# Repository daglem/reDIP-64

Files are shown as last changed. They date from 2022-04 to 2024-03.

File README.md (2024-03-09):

# reDIP 64

## Commodore 64 FPGA emulation platform
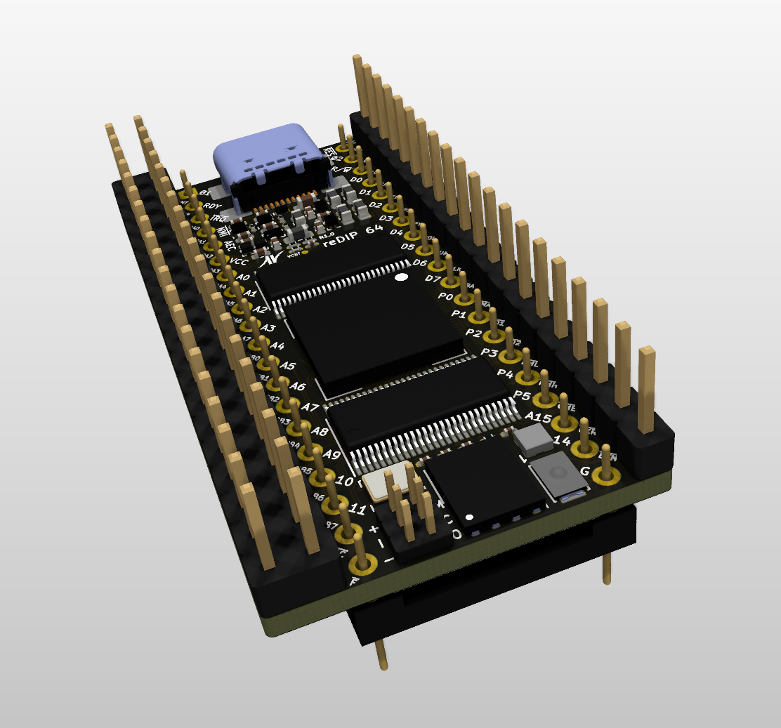
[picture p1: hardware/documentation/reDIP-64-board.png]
Board


## Overview

The reDIP 64 is an open source hardware development board which
combines the following in a tiny 25.40 x 50.80 mm footprint:

* Lattice ECP5-5G FPGA (LFE5UM5G-25)
* NXP PTN5110NHQ USB PD TCPC PHY
* NXP SGTL5000 Audio Codec
* 128Mbit FLASH
* 128Mbit HyperRAM
* RGB LED
* Push button
* USB-C receptacle for power, Full Speed USB, and DisplayPort (DP Alt Mode)
* Lots of 5V tolerant I/O

The reDIP 64 aims at functioning as

* A partial or full brain transplant for the venerable Commodore 64
* A "Retro computer on a chip", which can be used stand-alone or in
  custom retro computer builds
* A versatile generic FPGA platform with power, HID input, and audio /
  video output all handled through a single USB-C connector

Designs for the ECP5 FPGA can be processed by
[yosys](https://github.com/YosysHQ/yosys/) and
[nextpnr](https://github.com/YosysHQ/nextpnr/).

Also check out the [reDIP SID](https://github.com/daglem/reDIP-SID),
if you are interested in a platform for MOS 6581 / 8580 SID emulation
in particular.

## General use

### I/O interfaces

#### 100 header pins:

* 5V input / output
* 3.3V output
* 92 FPGA GPIO
* 5 audio pins (stereo line input, stereo line output, GND)
* GND

All FPGA I/O is 5V tolerant, and can drive 5V TTL.

Note that the audio line inputs are not AC coupled - AC coupling must
be externally added for audio applications. Without external AC
coupling, the line inputs can conceivably be used as generic ADCs.

#### JTAG:

A separate 6 pin header is provided for JTAG.

#### USB-C functions:

* 5V power in / out
* USB Power Delivery (PD)
* FPGA Full Speed USB
* FPGA DisplayPort (DP Alt Mode)

## Commodore 64 compatibility

The board is pin compatible with the MOS 6510 / 8500 MPU chip, and has
additional pin headers to cover all the custom chips and I/O in the
Commodore 64:

* 6510 / 8500 MPU
* 6567/6569 / 8562/8565 VIC-II
* 6581 / 8580 SID (x 2)
* 2 x 6526 CIA
* Cartridge port signals
* Menu / freeze button

For anyone interested in experimenting with a Commodore 64 setup,
while avoiding blown fuses and a broken reDIP 64 board:

* A 2A C64 power supply is recommended
* Be careful not to apply force to SMD components on insertion and removal - use a ZIF socket if possible

The idea is that one can start by mounting the reDIP 64 in a Commodore
64, replacing the 6510 / 8500 MPU. This will make it possible to communicate
with the Commodore 64 via USB, to output audio and video via the USB-C
connector (DP Alt Mode), and to emulate a second SID chip.

Then, if one wishes to replace the VIC-II, the SID, or a CIA chip, the
custom chip is removed, and wires are run from the reDIP 64 to the
corresponding socket pins for the custom chip.

Note that the audio line outputs cannot drive the C64 audio output
stage directly, however an audio output may be connected directly to
pin 3 of the C64 audio/video connector (preferably removing or cutting
a pin on C13 in the C64).

Also note that unless suggested GPIO is repurposed for other
functions, the VIC-II can only be replaced by additionally emulating
all RAM chips, and the PLA can only be replaced by emulating *all*
custom chips, including ROM and RAM.

The MOS 8502 MPU used in the Commodore C128 has a similar pinout to
the MOS 6510. Since the same pins are used for power, the reDIP 64 can
conceivably also be used in a C128.

## Retro computer on a chip

Power, HID input, and audio / video can all be handled via the USB-C
port, hence the reDIP 64 is in fact capable of operating as a retro
computer all on its own. Just connect the reDIP 64 to a DisplayPort
monitor, either directly or via an USB hub, and add a keyboard and any
other HID input devices. Now, all that is needed is an FPGA
implementation of a retro computer :wink:

To create a fully functional retro computer, i.e. with I/O which can
interface with original perhiperals, physical connectors and glue
logic must be added to the mix. This can make for some fun projects!

Using the suggested GPIO, a fully functional custom C64 can be built
using a minimum of additional components.

## Other FPGA projects

The board can be of course also be used to experiment with e.g.

* DisplayPort audio / video
* Analog audio
* USB Power Delivery
* Interfacing with 5V TTL
* RISC-V and other CPU architectures
* Other SoC projects

## Disclaimer

Please note that this is only my third board design - rookie mistakes
are probably made, and feedback is welcome.

## Board images

Board Front | Board Back
----------- | ----------
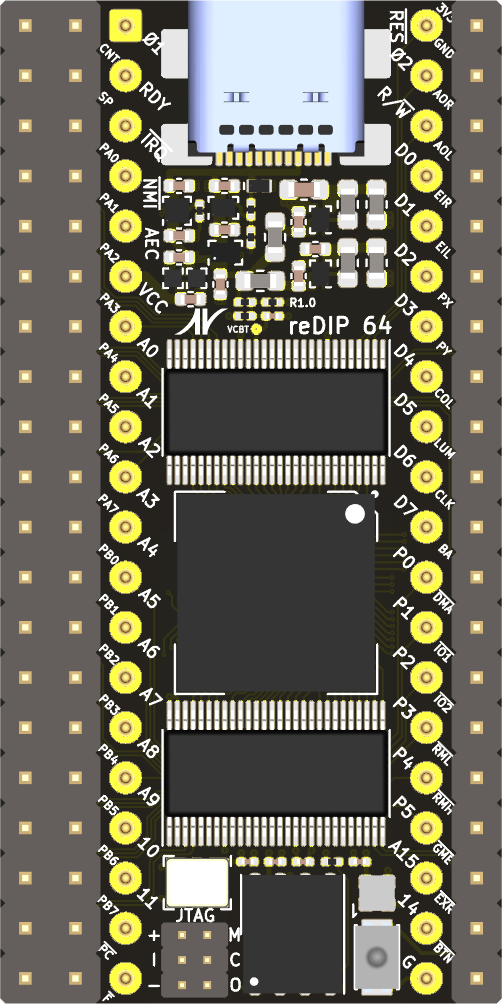
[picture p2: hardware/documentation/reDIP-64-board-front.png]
Board Front
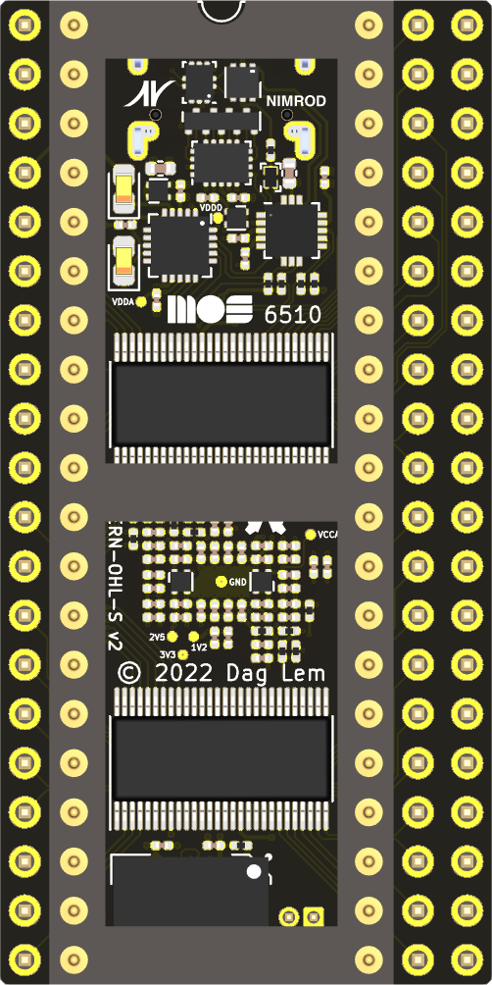
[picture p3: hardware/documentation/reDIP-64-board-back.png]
Board Back
 |

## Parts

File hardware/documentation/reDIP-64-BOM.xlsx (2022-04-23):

Prj: | reDIP 64 |  |  |  |  |  |  | Board Qty: | 100
Co.: | Nimrod |  |  |  |  |  |  | Unit Cost: | $30.45
Prj date: | lø. 23. april 2022 kl. 17.23 +0200 |  |  |  |  |  |  | Total Cost: | $3045.41 |  |  |  |  | $1220.08 | 22 of 53 parts found |  |  |  |  | $3181.63 | 52 of 53 parts found |  |  |  |  | $1467.26 | 38 of 53 parts found |  |  |  |  | $209.65 | 11 of 53 parts found |  |  |  |  | $2558.30 | 45 of 53 parts found |  |  |  |  | $1634.90 | 39 of 53 parts found |  |  |  |  | $346.20 | 18 of 53 parts found |  |  |  |  | $60.64 | 4 of 53 parts found
$ date: | 2022-04-23 17:23:41
Global Part Info |  |  |  |  |  |  |  |  |  | Arrow |  |  |  |  |  | Digi-Key |  |  |  |  |  | Farnell |  |  |  |  |  | LCSC |  |  |  |  |  | Mouser |  |  |  |  |  | Newark |  |  |  |  |  | RS Components |  |  |  |  |  | TME
Refs | Value | Desc | Notes | Footprint | Manf | Manf# | Qty | Unit$ | Ext$ | Avail | Purch | Unit$ | MOQ | Ext$ | Cat# | Avail | Purch | Unit$ | MOQ | Ext$ | Cat# | Avail | Purch | Unit$ | MOQ | Ext$ | Cat# | Avail | Purch | Unit$ | MOQ | Ext$ | Cat# | Avail | Purch | Unit$ | MOQ | Ext$ | Cat# | Avail | Purch | Unit$ | MOQ | Ext$ | Cat# | Avail | Purch | Unit$ | MOQ | Ext$ | Cat# | Avail | Purch | Unit$ | MOQ | Ext$ | Cat#
C1,C13,C19 | 1uF | CAP CER 2.2uF 25V 20% X5R 0402 | 5V DC DERATED TO 1uF | C_0402_1005Metric | Murata | GRM155R61E225ME11D (https://www.murata.com/products/productdetail.aspx?partno=GRM155R61E225ME11D) | 300 | $0.035 | $10.56 | 41127 |  | $0.092 | 1 | $27.63 | GRM155R61E225ME11D (https://octopart.com/click/track?ai=8078&sig=0bf2f55&sid=1106&ppid=46692831&vpid=473331984&ct=offers) | 163798 |  | $0.096 | 1 | $28.83 | 490-12704-1-ND (https://octopart.com/click/track?ai=8078&sig=00769d9&sid=459&ppid=46692831&vpid=242051473&ct=offers) | 20000 |  | $0.099 | 10 | $29.77 | 3582801 (https://octopart.com/click/track?c=1&ai=8078&sig=0068366&sid=819&ppid=46692831&vpid=670691908&ct=offers) | 6980 |  | $0.035 | 10 | $10.56 | C385033 (https://octopart.com/click/track?ai=8078&sig=05f9ad3&sid=27971&ppid=46692831&vpid=791860132&ct=offers) | 247394 |  | $0.100 | 1 | $30.00 | 81GRM155R61E225ME1D (https://octopart.com/click/track?ai=8078&sig=075e695&sid=2401&ppid=46692831&vpid=202849811&ct=offers) | 20000 |  | $0.100 | 1 | $30.00 | 03AJ1583 (https://octopart.com/click/track?c=1&ai=8078&sig=0cd1567&sid=2402&ppid=46692831&vpid=671481202&ct=offers)
C2,C4,C24,C26,C30,C31,C37,C39,C41,C43,C45,C47,C49,C51,C53,C55,C57,C61 | 1uF | CAP CER 2.2uF 6.3V 20% X5R 0201 | C24,C30: 1.2V DC DERATED TO 1.4uF C26: 2.5V DC DERATED TO 0.9uF C2,C4,C31,C37,C39,C41,C43,C45,C47,C49,C51,C53,C55,C57,C61: 3.3V DC DERATED TO 0.7uF | C_0201_0603Metric | Murata | GRM033R60J225ME01D (https://www.murata.com/products/productdetail.aspx?partno=GRM033R60J225ME01D) | 1800 | $0.029 | $51.84 |  |  |  |  |  |  | 11380 |  | $0.038 | 1 | $68.31 | 490-GRM033R60J225ME01DCT-ND (https://octopart.com/click/track?ai=8078&sig=07d2518&sid=459&ppid=111800792&vpid=790821740&ct=offers) |  |  |  |  |  |  | 12020 |  | $0.029 | 10 | $51.84 | C782150 (https://octopart.com/click/track?ai=8078&sig=014ed64&sid=27971&ppid=111800792&vpid=658813846&ct=offers) | 670 |  | $0.044 | 1 | $79.20 | 81GRM033R60J225ME1D (https://octopart.com/click/track?ai=8078&sig=0ead83f&sid=2401&ppid=111800792&vpid=707177137&ct=offers)
C3,C23,C25,C28,C29 | 1uF | CAP CER 2.2uF 10V 20% X5R 0201 | C23,C25,C28,C29: 3.3V DC DERATED TO 0.9uF C3: 5V DC DERATED TO 0.6uF | C_0201_0603Metric | Murata | GRM035R61A225ME01D (https://www.murata.com/products/productdetail.aspx?partno=GRM035R61A225ME01D) | 500
C5,C7-C11 | 100nF | CAP CER 100nF 6.3V 10% X5R 0201 |  | C_0201_0603Metric | Murata | GRM033R60J104KE19D (https://www.murata.com/products/productdetail.aspx?partno=GRM033R60J104KE19D) | 600 | $0.002 | $1.20 | 3960000 |  |  | 15000 |  | GRM033R60J104KE19D (https://octopart.com/click/track?ai=8078&sig=036c01f&sid=1106&ppid=196787&vpid=15059944&ct=offers) | 30960551 |  | $0.006 | 1 | $3.85 | 490-3167-1-ND (https://octopart.com/click/track?ai=8078&sig=0350220&sid=459&ppid=196787&vpid=1550152&ct=offers) | 105000 |  | $0.049 | 10 | $29.70 | 1775994 (https://octopart.com/click/track?ai=8078&sig=05fdde2&sid=819&ppid=196787&vpid=139136007&ct=offers) | 2617600 |  | $0.002 | 100 | $1.20 | C76928 (https://octopart.com/click/track?ai=8078&sig=0fec319&sid=27971&ppid=196787&vpid=445986843&ct=offers) | 6447225 |  | $0.009 | 1 | $5.40 | 81GRM033R60J104KE19 (https://octopart.com/click/track?ai=8078&sig=013ebb0&sid=2401&ppid=196787&vpid=38925187&ct=offers) | 105000 |  | $0.012 | 1 | $7.20 | 51R6558 (https://octopart.com/click/track?ai=8078&sig=09cce70&sid=2402&ppid=196787&vpid=20869753&ct=offers) |  |  |  |  |  |  | 25600 |  | $0.013 | 100 | $7.50 | GRM033R60J104KE19D (https://octopart.com/click/track?ai=8078&sig=079c19d&sid=1532&ppid=196787&vpid=709097614&ct=offers)
C6,C32-C36,C38,C40,C42,C44,C46,C48,C50,C52,C54,C56,C58-C60,C62-C68 | 0.1uF | CAP CER 0.22uF 6.3V 20% X5R 0201 | C68: 1.5V DC VAG DERATED TO 0.1uF C6,C32-C36,C38,C40,C42,C44,C46,C48,C50,C52,C54,C56,C58,C62-C67: 3.3V DC DERATED TO 0.1uF C59,C60: 4.3V DC DERATED TO 0.1uF | C_0201_0603Metric | Murata | GRM033R60J224KE15D (https://www.murata.com/products/productdetail.aspx?partno=GRM033R60J224KE15D) | 2600 | $0.004 | $9.36 | 115702 |  |  | 15000 |  | GRM033R60J224KE15D (https://octopart.com/click/track?ai=8078&sig=0c86c84&sid=1106&ppid=51454422&vpid=480521207&ct=offers) | 2560342 |  | $0.007 | 1 | $19.29 | 490-10406-1-ND (https://octopart.com/click/track?ai=8078&sig=0492ec2&sid=459&ppid=51454422&vpid=172161550&ct=offers) | 210000 |  | $0.007 | 10 | $17.43 | 2990684 (https://octopart.com/click/track?ai=8078&sig=00c315f&sid=11744&ppid=51454422&vpid=528084476&ct=offers) | 21400 |  | $0.004 | 100 | $9.36 | C76931 (https://octopart.com/click/track?ai=8078&sig=0f2788c&sid=27971&ppid=51454422&vpid=445986847&ct=offers) | 350207 |  | $0.009 | 1 | $23.40 | 81GRM33R60J224KE15D (https://octopart.com/click/track?ai=8078&sig=0207666&sid=2401&ppid=51454422&vpid=178169497&ct=offers) | 210000 |  | $0.015 | 1 | $39.00 | 94AC8892 (https://octopart.com/click/track?ai=8078&sig=0d37eed&sid=2402&ppid=51454422&vpid=529126546&ct=offers) | 21000 |  | $0.009 | 1000 | $23.46 | 1852023 (https://octopart.com/click/track?ai=8078&sig=0fe5791&sid=10022&ppid=51454422&vpid=562632809&ct=offers)
C12,C21 | 2.2uF | CAP CER 10uF 6.3V 20% X5R 0402 | 5V DC DERATED TO 1.9uF | C_0402_1005Metric | Murata | GRM155R60J106ME05J (https://www.murata.com/products/productdetail.aspx?partno=GRM155R60J106ME05J) | 200 | $0.037 | $7.34 |  |  |  |  |  |  | NonStk |  | $0.037 | 1 | $7.34 | 490-GRM155R60J106ME05JCT-ND (https://octopart.com/click/track?c=1&ai=8078&sig=07356ec&sid=459&ppid=106705433&vpid=699998639&ct=offers) | NonStk |  |  | 40000 |  | 3785797 (https://octopart.com/click/track?c=1&ai=8078&sig=0cc048c&sid=819&ppid=106705433&vpid=757047412&ct=offers) |  |  |  |  |  |  | 19303 |  | $0.039 | 1 | $7.80 | 81GRM155R60J106ME05 (https://octopart.com/click/track?ai=8078&sig=02e2548&sid=2401&ppid=106705433&vpid=609821795&ct=offers)
C14-C17,C20,C27 | 1uF | CAP CER 2.2uF 16V 10% X6S 0402 | 5V DC DERATED TO 1uF | C_0402_1005Metric | Murata | GRM155C81C225KE11D (https://www.murata.com/products/productdetail.aspx?partno=GRM155C81C225KE11D) | 600 | $0.059 | $35.57 | 9005 |  | $0.092 | 1 | $55.44 | GRM155C81C225KE11D (https://octopart.com/click/track?ai=8078&sig=0017922&sid=1106&ppid=46692789&vpid=485848787&ct=offers) | 21504 |  | $0.066 | 1 | $39.47 | 490-14595-1-ND (https://octopart.com/click/track?ai=8078&sig=0b165bb&sid=459&ppid=46692789&vpid=410305221&ct=offers) | 45449 |  | $0.059 | 10 | $35.57 | 3581345 (https://octopart.com/click/track?ai=8078&sig=0d9d05a&sid=819&ppid=46692789&vpid=666721052&ct=offers) |  |  |  |  |  |  | 2615 |  | $0.097 | 1 | $58.20 | 81GRM155C81C225KE1D (https://octopart.com/click/track?ai=8078&sig=0cdb919&sid=2401&ppid=46692789&vpid=230758256&ct=offers) | 45429 |  | $0.097 | 10 | $58.20 | 92AH5000 (https://octopart.com/click/track?ai=8078&sig=0849c23&sid=2402&ppid=46692789&vpid=669036303&ct=offers)
C18 | 10uF | CAP CER 22uF 6.3V 20% X5R 0603 | 3.3V DC DERATED TO 8uF | C_0603_1608Metric | Murata | GRM188R60J226ME15D (https://www.murata.com/products/productdetail.aspx?partno=GRM188R60J226ME15D) | 100 | $0.051 | $5.11 | 15798 |  | $0.121 | 1 | $12.07 | GRM188R60J226ME15D (https://octopart.com/click/track?ai=8078&sig=01f04b3&sid=1106&ppid=49426892&vpid=474278961&ct=offers) | 9752 |  | $0.075 | 1 | $7.48 | 490-GRM188R60J226ME15DCT-ND (https://octopart.com/click/track?ai=8078&sig=0eb85fb&sid=459&ppid=49426892&vpid=697100878&ct=offers) | 11110 |  | $0.116 | 10 | $11.60 | 3581375 (https://octopart.com/click/track?ai=8078&sig=0532207&sid=819&ppid=49426892&vpid=666721183&ct=offers) | 6610 |  | $0.051 | 10 | $5.11 | C440187 (https://octopart.com/click/track?ai=8078&sig=0b3ce4c&sid=27971&ppid=49426892&vpid=719729088&ct=offers) | 2004 |  | $0.118 | 1 | $11.80 | 81GRM188R60J226ME5D (https://octopart.com/click/track?ai=8078&sig=05605b1&sid=2401&ppid=49426892&vpid=248621702&ct=offers) | 11110 |  | $0.118 | 10 | $11.80 | 92AH5101 (https://octopart.com/click/track?ai=8078&sig=01d4b29&sid=2402&ppid=49426892&vpid=669036403&ct=offers)
C22 | 10uF | CAP CER 10uF 4V 20% X5R 0402 | 1.2V DC DERATED TO 7.5uF | C_0402_1005Metric | Murata | GRM155R60G106ME01D (https://www.murata.com/products/productdetail.aspx?partno=GRM155R60G106ME01D) | 100 | $0.046 | $4.60 |  |  |  |  |  |  | NonStk |  |  | 10000 |  | 490-GRM155R60G106ME01DTR-ND (https://octopart.com/click/track?c=1&ai=8078&sig=0926ac3&sid=459&ppid=106705429&vpid=697018846&ct=offers) | NonStk |  |  | 10000 |  | 3785795 (https://octopart.com/click/track?c=1&ai=8078&sig=00736b6&sid=819&ppid=106705429&vpid=757047408&ct=offers) |  |  |  |  |  |  | NonStk |  | $0.046 | 1 | $4.60 | 81GRM155R60G106ME1D (https://octopart.com/click/track?c=1&ai=8078&sig=0db3e0c&sid=2401&ppid=106705429&vpid=601104790&ct=offers)
C69,C70 | 10uF | CAP TANT 10uF 6.3V 20% 0603 | 1.65V DC 1.5V AC AUDIO | CP_EIA-1608-08_AVX-J | Vishay | TMCJ0J106MTRF (https://www.vishay.com/docs/40176/tmcj.pdf) | 200 | $0.153 | $30.68 |  |  |  |  |  |  | NonStk |  | $0.162 | 1 | $32.36 | 718-2355-1-ND (https://octopart.com/click/track?c=1&ai=8078&sig=0f93a07&sid=459&ppid=51468669&vpid=542012103&ct=offers) | NonStk |  | $0.166 | 10 | $33.25 | 2491414 (https://octopart.com/click/track?c=1&ai=8078&sig=0142d8e&sid=819&ppid=51468669&vpid=227400135&ct=offers) |  |  |  |  |  |  | NonStk |  | $0.162 | 1 | $32.40 | 74TMCJ0J106MTRF (https://octopart.com/click/track?c=1&ai=8078&sig=0449c4a&sid=2401&ppid=51468669&vpid=222364962&ct=offers) | NonStk |  | $0.162 | 10 | $32.40 | 56Y0084 (https://octopart.com/click/track?c=1&ai=8078&sig=01aab72&sid=2402&ppid=51468669&vpid=228374112&ct=offers) | 20 |  | $0.153 | 20 | $30.68 | 1882240 (https://octopart.com/click/track?ai=8078&sig=074f439&sid=10022&ppid=51468669&vpid=562995447&ct=offers)
D1 | ESD7241 | DIODE ESD VRWM 24V X2DFN2 |  | CASE_714AB_1.0x0.6mm | onsemi | ESD7241N2T5G (https://www.onsemi.com/pdf/datasheet/esd7241-d.pdf) | 100 | $0.172 | $17.20 |  |  |  |  |  |  | NonStk |  | $0.206 | 1 | $20.56 | ESD7241N2T5GOSCT-ND (https://octopart.com/click/track?c=1&ai=8078&sig=0c32aac&sid=459&ppid=75535408&vpid=469782186&ct=offers) | NonStk |  | $0.271 | 5 | $27.07 | 3368198 (https://octopart.com/click/track?c=1&ai=8078&sig=0f97155&sid=11744&ppid=75535408&vpid=612326448&ct=offers) |  |  |  |  |  |  | 3983 |  | $0.206 | 1 | $20.60 | 863ESD7241N2T5G (https://octopart.com/click/track?ai=8078&sig=06bf997&sid=2401&ppid=75535408&vpid=419117981&ct=offers) | NonStk |  | $0.172 | 1 | $17.20 | 54AH8588 (https://octopart.com/click/track?c=1&ai=8078&sig=09122bc&sid=2402&ppid=75535408&vpid=625770976&ct=offers)
D2 | VESD05A6-HAF | IC ESD ARRAY VRWM 5V LLP75-7L |  | LLP75-7L | Vishay | VESD05A6-HAF-GS08 (https://www.vishay.com/docs/81311/vesd05a6.pdf) | 100 | $0.153 | $15.27 | 14503 |  | $0.319 | 1 | $31.94 | VESD05A6HAFGS08 (https://octopart.com/click/track?ai=8078&sig=0c8659d&sid=1106&ppid=42182781&vpid=482031279&ct=offers) | 2 |  | $0.354 | 1 | $35.42 | VESD05A6-HAF-GS08GICT-ND (https://octopart.com/click/track?ai=8078&sig=066da7a&sid=459&ppid=42182781&vpid=159788920&ct=offers) |  |  |  |  |  |  | 15000 |  | $0.153 | 1 | $15.27 | C1974940 (https://octopart.com/click/track?ai=8078&sig=073b182&sid=27971&ppid=42182781&vpid=804285873&ct=offers) | 2755 |  | $0.355 | 1 | $35.50 | 78VESD05A6HAF (https://octopart.com/click/track?ai=8078&sig=0f8b020&sid=2401&ppid=42182781&vpid=115161063&ct=offers) | NonStk |  |  | 15000 |  | 64M7155 (https://octopart.com/click/track?c=1&ai=8078&sig=0d9f854&sid=2402&ppid=42182781&vpid=249320425&ct=offers) | 120 |  | $0.360 | 20 | $35.96 | 1808156 (https://octopart.com/click/track?ai=8078&sig=0c0d9dc&sid=10022&ppid=42182781&vpid=757114302&ct=offers)
D3 | D3V3F8U9LP3810 | IC ESD ARRAY VRWM 3.3V U-DFN3810-09 |  | U-DFN3810-9 | Diodes | D3V3F8U9LP3810-7 (https://www.diodes.com/assets/Datasheets/D3V3F8U9LP3810.pdf) | 100 | $0.166 | $16.60 | 757 |  | $0.182 | 1 | $18.16 | D3V3F8U9LP38107 (https://octopart.com/click/track?ai=8078&sig=0375af7&sid=1106&ppid=91620605&vpid=486677128&ct=offers) | 515 |  | $0.219 | 1 | $21.94 | D3V3F8U9LP3810-7DICT-ND (https://octopart.com/click/track?ai=8078&sig=02b6308&sid=459&ppid=91620605&vpid=479893368&ct=offers) |  |  |  |  |  |  |  |  |  |  |  |  | 1234 |  | $0.220 | 1 | $22.00 | 621D3V3F8U9LP38107 (https://octopart.com/click/track?ai=8078&sig=045c227&sid=2401&ppid=91620605&vpid=478299237&ct=offers) | NonStk |  | $0.166 | 5 | $16.60 | 28AK9075 (https://octopart.com/click/track?c=1&ai=8078&sig=09c877a&sid=2402&ppid=91620605&vpid=804248950&ct=offers) | 752 |  | $0.321 | 50 | $32.09 | 1827487 (https://octopart.com/click/track?ai=8078&sig=09f71ac&sid=10022&ppid=91620605&vpid=529868522&ct=offers)
D4 | SMD-LX0707RGB-TR | IC LED RGB 0707 | REPLACEMENT PARTS: Everlight 19-C47/RSGHBHC-5V01/2T, Everlight EAST1818RGBICA0 | SMD-LX0707RGB-TR | Lumex | SMD-LX0707RGB-TR (https://www.lumex.com/datasheet/SMD-LX0707RGB-TR.html) | 100 | $0.236 | $23.61 |  |  |  |  |  |  | 95408 |  | $0.315 | 1 | $31.45 | 67-2331-1-ND (https://octopart.com/click/track?ai=8078&sig=011841b&sid=459&ppid=98770141&vpid=527582517&ct=offers) | NonStk |  | $0.447 | 1 | $44.72 | 3216559 (https://octopart.com/click/track?c=1&ai=8078&sig=08846a9&sid=819&ppid=98770141&vpid=575179783&ct=offers) |  |  |  |  |  |  | 1129 |  | $0.315 | 1 | $31.50 | 696SMDLX0707RGBTR (https://octopart.com/click/track?ai=8078&sig=01b9309&sid=2401&ppid=98770141&vpid=527691918&ct=offers) | NonStk |  | $0.315 | 1 | $31.50 | 02AH5948 (https://octopart.com/click/track?c=1&ai=8078&sig=0c78da6&sid=2402&ppid=98770141&vpid=547451562&ct=offers) |  |  |  |  |  |  | NonStk |  | $0.236 | 1 | $23.61 | SMDLX0707RGBTR (https://octopart.com/click/track?ai=8078&sig=0f2b5ee&sid=1532&ppid=98770141&vpid=709065371&ct=offers)
FB1-FB4 | BLM18KG601SN1 | FERRITE BEAD 600Ω 1.3A 0603 |  | L_0603_1608Metric | Murata | BLM18KG601SN1D (https://www.murata.com/products/productdetail.aspx?partno=BLM18KG601SN1%23) | 400 | $0.017 | $6.84 |  |  |  |  |  |  | NonStk |  | $0.038 | 1 | $15.20 | 490-5258-1-ND (https://octopart.com/click/track?c=1&ai=8078&sig=05de17f&sid=459&ppid=12276433&vpid=34232882&ct=offers) | NonStk |  | $0.032 | 10 | $12.89 | 1781094 (https://octopart.com/click/track?c=1&ai=8078&sig=05f8942&sid=11744&ppid=12276433&vpid=132490409&ct=offers) | 237800 |  | $0.017 | 50 | $6.84 | C85833 (https://octopart.com/click/track?ai=8078&sig=0061b01&sid=27971&ppid=12276433&vpid=445986611&ct=offers) | NonStk |  | $0.035 | 1 | $14.00 | 81BLM18KG601SN1D (https://octopart.com/click/track?c=1&ai=8078&sig=09647bb&sid=2401&ppid=12276433&vpid=37789808&ct=offers) | NonStk |  | $0.035 | 1 | $14.00 | 55R1514 (https://octopart.com/click/track?c=1&ai=8078&sig=036829a&sid=2402&ppid=12276433&vpid=21384392&ct=offers) | NonStk |  | $0.032 | 100 | $12.89 | 7474720 (https://octopart.com/click/track?c=1&ai=8078&sig=0cd141a&sid=10022&ppid=12276433&vpid=199071093&ct=offers) | 2850 |  | $0.050 | 50 | $19.92 | BLM18KG601SN1D (https://octopart.com/click/track?ai=8078&sig=055d269&sid=1532&ppid=12276433&vpid=709097365&ct=offers)
J1 | USB4080 | CONN USB-C | REPLACEMENT PART: HRO TYPE-C-31-M-05 | USB_C_Receptacle_GCT_USB4080 | GCT | USB4080-03-A (https://gct.co/connector/usb4080) | 100 | $0.616 | $61.60 |  |  |  |  |  |  | NonStk |  | $0.924 | 1 | $92.40 | 2073-USB4080-03-ACT-ND (https://octopart.com/click/track?c=1&ai=8078&sig=0694e8c&sid=459&ppid=119997701&vpid=748212182&ct=offers) | NonStk |  | $0.757 | 1 | $75.66 | 3801072 (https://octopart.com/click/track?c=1&ai=8078&sig=0e37a85&sid=819&ppid=119988781&vpid=767729240&ct=offers) |  |  |  |  |  |  | 1590 |  | $0.879 | 1 | $87.90 | 640USB408003A (https://octopart.com/click/track?ai=8078&sig=01b79f2&sid=2401&ppid=119997701&vpid=748837880&ct=offers) | 1575 |  | $0.616 | 1 | $61.60 | 59AJ3622 (https://octopart.com/click/track?ai=8078&sig=0fd0602&sid=2402&ppid=119988781&vpid=748501826&ct=offers)
J2 | Conn_02x20_Counter_Clockwise | CONN DIP ADAPTER ROUND PIN 0.5mm 40 POS .100" GOLD |  | DIP-40_W15.24mm_Header | CnC-Tech | 220-1-40-006 (https://cnctech.us/productdetails.asp?ID=772) | 100 | $2.430 | $243.00 | 2397 |  | $2.430 | 1 | $243.00 | 220140006 (https://octopart.com/click/track?ai=8078&sig=020cc6f&sid=1106&ppid=23165433&vpid=476303886&ct=offers) | 1643 |  | $2.788 | 1 | $278.76 | 1175-1527-5-ND (https://octopart.com/click/track?ai=8078&sig=0eef7b9&sid=459&ppid=23165433&vpid=69867392&ct=offers)
J3 | Conn_01x20 | CONN HDR SQ PIN 0.64mm 20 POS .100" GOLD MATING 6mm TAIL 3mm |  | PinHeader_1x20_P2.54mm_Vertical | Sullins | PRPC010SAAN-RC (https://drawings-pdf.s3.amazonaws.com/11635.pdf) | 100 | $0.190 | $18.96 |  |  |  |  |  |  | 7204 |  | $0.190 | 1 | $18.96 | S1011EC-10-ND (https://octopart.com/click/track?ai=8078&sig=076316f&sid=459&ppid=22265699&vpid=47550685&ct=offers)
J4 | Conn_02x20_Odd_Even | CONN HDR SQ PIN 0.64mm 2x20 POS .100" GOLD MATING 6mm TAIL 3mm |  | PinHeader_2x20_P2.54mm_Vertical | Sullins | PRPC020DAAN-RC (https://drawings-pdf.s3.amazonaws.com/11636.pdf) | 100 | $0.681 | $68.11 |  |  |  |  |  |  | 1318 |  | $0.681 | 1 | $68.11 | S2011EC-20-ND (https://octopart.com/click/track?ai=8078&sig=01fc03d&sid=459&ppid=22265834&vpid=47550820&ct=offers)
J5 | Conn_02x05_Odd_Even | CONN HDR SQ PIN 2x3 POS .050" GOLD MATING 3mm |  | PinHeader_2x03_P1.27mm_Vertical | Sullins | GRPB032VWVN-RC (https://s3.amazonaws.com/catalogspreads-pdf/PAGE94-95%20.050%20MALE%20HDR%20ST%20RA%20SMT.pdf) | 100 | $0.344 | $34.36 |  |  |  |  |  |  | 37934 |  | $0.344 | 1 | $34.36 | S9015E-03-ND (https://octopart.com/click/track?ai=8078&sig=0a66c24&sid=459&ppid=12650566&vpid=33973679&ct=offers)
L1 | 1uH | INDUCTOR 1uH 1.6A 0603 | NEW PART #: LSCNB1608HKT1R0MD | L_0603_1608Metric | Taiyo-Yuden | MCHK1608T1R0MKN (https://ds.yuden.co.jp/TYCOMPAS/ut/detail?pn=LSCNB1608HKT1R0MD&u=M) | 100 | $0.248 | $24.80 |  |  |  |  |  |  | 7627 |  | $0.273 | 1 | $27.26 | 587-MCHK1608T1R0MKNCT-ND (https://octopart.com/click/track?ai=8078&sig=045c1fe&sid=459&ppid=109373546&vpid=667948831&ct=offers) | 317 |  | $0.260 | 1 | $26.04 | 3666004 (https://octopart.com/click/track?ai=8078&sig=0e39665&sid=11744&ppid=109373546&vpid=700356037&ct=offers) |  |  |  |  |  |  | 15060 |  | $0.248 | 1 | $24.80 | 963MCHK1608T1R0MKN (https://octopart.com/click/track?ai=8078&sig=0177ca0&sid=2401&ppid=109373546&vpid=658751706&ct=offers) | 317 |  | $0.248 | 1 | $24.80 | 19AJ5819 (https://octopart.com/click/track?ai=8078&sig=0b45e3a&sid=2402&ppid=109373546&vpid=692918870&ct=offers)
L2 | 470nH | INDUCTOR 470nH 1.6A 0603 | NEW PART #: LSCNA1608FKTR47MA | L_0603_1608Metric | Taiyo-Yuden | MCFK1608TR47M (https://ds.yuden.co.jp/TYCOMPAS/ut/detail?pn=LSCNA1608FKTR47MA&u=M) | 100 | $0.223 | $22.30 |  |  |  |  |  |  | 6335 |  | $0.245 | 1 | $24.51 | 587-5625-1-ND (https://octopart.com/click/track?ai=8078&sig=0fd1c36&sid=459&ppid=81855409&vpid=421147784&ct=offers) | 4000 |  | $0.233 | 1 | $23.33 | 3919439 (https://octopart.com/click/track?ai=8078&sig=048df07&sid=819&ppid=81855409&vpid=787118673&ct=offers) |  |  |  |  |  |  | 10648 |  | $0.223 | 1 | $22.30 | 963MCFK1608TR47M (https://octopart.com/click/track?ai=8078&sig=0e5af96&sid=2401&ppid=81855409&vpid=421236231&ct=offers) | 4000 |  | $0.223 | 1 | $22.30 | 40AH3383 (https://octopart.com/click/track?ai=8078&sig=046f483&sid=2402&ppid=81855409&vpid=593549417&ct=offers)
Q1 | PDTA143ZMB | TRANSISTOR PNP RET R1=4.7kΩ R2=47kΩ 100mA SOT883B |  | SOT-883 | Nexperia | PDTA143ZMB,315 (https://assets.nexperia.com/documents/data-sheet/PDTA143ZMB.pdf) | 100 | $0.035 | $3.50 |  |  |  |  |  |  | NonStk |  |  | 10000 |  | PDTA143ZMB,315-ND (https://octopart.com/click/track?c=1&ai=8078&sig=0944463&sid=459&ppid=78754604&vpid=413679736&ct=offers) |  |  |  |  |  |  |  |  |  |  |  |  | 9989 |  | $0.119 | 1 | $11.90 | 771PDTA143ZMB315 (https://octopart.com/click/track?ai=8078&sig=0d6ccfc&sid=2401&ppid=78754604&vpid=504003500&ct=offers) | NonStk |  | $0.035 | 1 | $3.50 | 29AK3066 (https://octopart.com/click/track?c=1&ai=8078&sig=039799e&sid=2402&ppid=78754604&vpid=804259804&ct=offers)
R1,R2 | 2.2k | RES 2.2kΩ 50mW 5% 0201 |  | R_0201_0603Metric | Panasonic | ERJ1GNJ222C (https://industrial.panasonic.com/ww/products/pt/general-purpose-chip-resistors/models/ERJ1GNJ222C) | 200 | $0.011 | $2.12 | 63696 |  | $0.011 | 1 | $2.12 | ERJ1GNJ222C (https://octopart.com/click/track?ai=8078&sig=05ea2d5&sid=1106&ppid=44403350&vpid=473398349&ct=offers) | 107438 |  | $0.014 | 1 | $2.80 | P123277CT-ND (https://octopart.com/click/track?ai=8078&sig=0fe0904&sid=459&ppid=44403350&vpid=465235292&ct=offers) | NonStk |  |  | 30000 |  | 3303211 (https://octopart.com/click/track?c=1&ai=8078&sig=098df08&sid=819&ppid=44403350&vpid=603690887&ct=offers) |  |  |  |  |  |  | 2112 |  | $0.013 | 1 | $2.60 | 667ERJ1GNJ222C (https://octopart.com/click/track?ai=8078&sig=07d1d1b&sid=2401&ppid=44403350&vpid=248150297&ct=offers) | NonStk |  |  | 15000 |  | 51W5827 (https://octopart.com/click/track?c=1&ai=8078&sig=01bc52e&sid=2402&ppid=44403350&vpid=632042349&ct=offers) | 28000 |  |  | 1000 |  | 1797128 (https://octopart.com/click/track?ai=8078&sig=0a098df&sid=10022&ppid=44403350&vpid=577025041&ct=offers)
R3,R4,R11,R14 | 10k | RES 10kΩ 50mW 5% 0201 |  | R_0201_0603Metric | Panasonic | ERJ1GNJ103C (https://industrial.panasonic.com/ww/products/pt/general-purpose-chip-resistors/models/ERJ1GNJ103C) | 400 | $0.003 | $1.20 | 54130 |  | $0.003 | 1 | $1.20 | ERJ1GNJ103C (https://octopart.com/click/track?ai=8078&sig=0afa606&sid=1106&ppid=44322539&vpid=474279624&ct=offers) | 509328 |  | $0.014 | 1 | $5.60 | P123222CT-ND (https://octopart.com/click/track?ai=8078&sig=0301d78&sid=459&ppid=44322539&vpid=465235182&ct=offers) | NonStk |  |  | 30000 |  | 3303150 (https://octopart.com/click/track?c=1&ai=8078&sig=0fd9335&sid=819&ppid=44322539&vpid=603690832&ct=offers) | 750 |  | $0.019 | 50 | $7.72 | C242159 (https://octopart.com/click/track?ai=8078&sig=06c973b&sid=27971&ppid=44322539&vpid=495511688&ct=offers) | 826049 |  | $0.013 | 1 | $5.20 | 667ERJ1GNJ103C (https://octopart.com/click/track?ai=8078&sig=0a64394&sid=2401&ppid=44322539&vpid=120580014&ct=offers) | NonStk |  | $0.008 | 1 | $3.20 | 51W5775 (https://octopart.com/click/track?c=1&ai=8078&sig=050ae47&sid=2402&ppid=44322539&vpid=173683819&ct=offers) | 71000 |  |  | 1000 |  | 1797135 (https://octopart.com/click/track?ai=8078&sig=0c48158&sid=10022&ppid=44322539&vpid=577025032&ct=offers)
R5 | 1.5k | RES 1.5kΩ 50mW 5% 0201 |  | R_0201_0603Metric | Panasonic | ERJ1GNJ152C (https://industrial.panasonic.com/ww/products/pt/general-purpose-chip-resistors/models/ERJ1GNJ152C) | 100 | $0.005 | $0.50 | 60000 |  | $0.010 | 1 | $1.03 | ERJ1GNJ152C (https://octopart.com/click/track?ai=8078&sig=0b212f8&sid=1106&ppid=55940368&vpid=507401781&ct=offers) | 143710 |  | $0.014 | 1 | $1.40 | P123246CT-ND (https://octopart.com/click/track?ai=8078&sig=06f5537&sid=459&ppid=55940368&vpid=465235230&ct=offers) | NonStk |  |  | 30000 |  | 3303177 (https://octopart.com/click/track?c=1&ai=8078&sig=031cc2c&sid=819&ppid=55940368&vpid=603690856&ct=offers) |  |  |  |  |  |  | 22832 |  | $0.013 | 1 | $1.30 | 667ERJ1GNJ152C (https://octopart.com/click/track?ai=8078&sig=01a465a&sid=2401&ppid=55940368&vpid=165486557&ct=offers) | NonStk |  | $0.005 | 1 | $0.50 | 51W5799 (https://octopart.com/click/track?c=1&ai=8078&sig=0e5d5c9&sid=2402&ppid=55940368&vpid=192308633&ct=offers) | 28000 |  |  | 1000 |  | 1797145 (https://octopart.com/click/track?ai=8078&sig=08f769b&sid=10022&ppid=55940368&vpid=577025035&ct=offers)
R6,R7,R24 | 22 | RES 22Ω 50mW 5% 0201 |  | R_0201_0603Metric | Panasonic | ERJ1GNJ220C (https://industrial.panasonic.com/ww/products/pt/general-purpose-chip-resistors/models/ERJ1GNJ220C) | 300 | $0.009 | $2.70 | 60000 |  | $0.010 | 1 | $3.03 | ERJ1GNJ220C (https://octopart.com/click/track?ai=8078&sig=0b40981&sid=1106&ppid=42505965&vpid=473398346&ct=offers) | NonStk |  | $0.014 | 1 | $4.20 | P123275CT-ND (https://octopart.com/click/track?c=1&ai=8078&sig=04cd504&sid=459&ppid=42505965&vpid=465235288&ct=offers) | NonStk |  |  | 30000 |  | 3303209 (https://octopart.com/click/track?c=1&ai=8078&sig=0433a1d&sid=819&ppid=42505965&vpid=603690885&ct=offers) |  |  |  |  |  |  | 83 |  | $0.013 | 1 | $3.90 | 667ERJ1GNJ220C (https://octopart.com/click/track?ai=8078&sig=0d716f6&sid=2401&ppid=42505965&vpid=165486571&ct=offers) | NonStk |  | $0.009 | 1 | $2.70 | 51W5825 (https://octopart.com/click/track?c=1&ai=8078&sig=0965e6c&sid=2402&ppid=42505965&vpid=524371516&ct=offers) | 44000 |  |  | 1000 |  | 1797158 (https://octopart.com/click/track?ai=8078&sig=09ab0d1&sid=10022&ppid=42505965&vpid=577025038&ct=offers)
R8,R12,R13 | 100 | RES 100Ω 50mW 1% 0201 |  | R_0201_0603Metric | Panasonic | ERJ1GNF1000C (https://industrial.panasonic.com/ww/products/pt/general-purpose-chip-resistors/models/ERJ1GNF1000C) | 300 | $0.022 | $6.60 | 33 |  |  | 15000 |  | ERJ1GNF1000C (https://octopart.com/click/track?ai=8078&sig=0ff7a00&sid=1106&ppid=55419695&vpid=473398243&ct=offers) | 634811 |  | $0.027 | 1 | $7.98 | P122654CT-ND (https://octopart.com/click/track?ai=8078&sig=0ed396b&sid=459&ppid=55419695&vpid=465234046&ct=offers) | 7750 |  | $0.025 | 10 | $7.58 | 2302309 (https://octopart.com/click/track?ai=8078&sig=09fe313&sid=11744&ppid=55419695&vpid=132575569&ct=offers) |  |  |  |  |  |  | 619255 |  | $0.025 | 1 | $7.50 | 667ERJ1GNF1000C (https://octopart.com/click/track?ai=8078&sig=0a77d19&sid=2401&ppid=55419695&vpid=187838583&ct=offers) | 25381 |  | $0.022 | 1 | $6.60 | 05X8794 (https://octopart.com/click/track?ai=8078&sig=0a75cd0&sid=2402&ppid=55419695&vpid=191369176&ct=offers) | 54000 |  |  | 1000 |  | 1797123 (https://octopart.com/click/track?ai=8078&sig=0dabfaa&sid=10022&ppid=55419695&vpid=577025001&ct=offers)
R9,R10 | 100k | RES 100kΩ 50mW 5% 0201 |  | R_0201_0603Metric | Panasonic | ERJ1GNJ104C (https://industrial.panasonic.com/ww/products/pt/general-purpose-chip-resistors/models/ERJ1GNJ104C) | 200 | $0.004 | $0.76 | 30000 |  | $0.025 | 1 | $5.08 | ERJ1GNJ104C (https://octopart.com/click/track?ai=8078&sig=09cad63&sid=1106&ppid=44275189&vpid=485941161&ct=offers) | 223639 |  | $0.014 | 1 | $2.80 | P123223CT-ND (https://octopart.com/click/track?ai=8078&sig=0ea42f0&sid=459&ppid=44275189&vpid=465235184&ct=offers) | NonStk |  |  | 30000 |  | 3303151 (https://octopart.com/click/track?c=1&ai=8078&sig=0769873&sid=819&ppid=44275189&vpid=603690833&ct=offers) | 14250 |  | $0.004 | 50 | $0.76 | C713501 (https://octopart.com/click/track?ai=8078&sig=0c08398&sid=27971&ppid=44275189&vpid=669037579&ct=offers) | 135368 |  | $0.013 | 1 | $2.60 | 667ERJ1GNJ104C (https://octopart.com/click/track?ai=8078&sig=099c1ff&sid=2401&ppid=44275189&vpid=118165429&ct=offers) | NonStk |  | $0.008 | 1 | $1.60 | 51W5776 (https://octopart.com/click/track?c=1&ai=8078&sig=0c8bb71&sid=2402&ppid=44275189&vpid=166626674&ct=offers) | 18000 |  |  | 1000 |  | 1797138 (https://octopart.com/click/track?ai=8078&sig=0c2b9be&sid=10022&ppid=44275189&vpid=577025033&ct=offers)
R15 | 3.83k | RES 3.83kΩ 50mW 1% 0201 |  | R_0201_0603Metric | Panasonic | ERJ1GNF3831C (https://industrial.panasonic.com/ww/products/pt/general-purpose-chip-resistors/models/ERJ1GNF3831C) | 100 | $0.025 | $2.50 |  |  |  |  |  |  | 2944 |  | $0.027 | 1 | $2.66 | P122977CT-ND (https://octopart.com/click/track?ai=8078&sig=0296014&sid=459&ppid=44403109&vpid=465234692&ct=offers) | NonStk |  |  | 30000 |  | 3302931 (https://octopart.com/click/track?c=1&ai=8078&sig=0bc16c5&sid=819&ppid=44403109&vpid=603690635&ct=offers) |  |  |  |  |  |  | 29560 |  | $0.025 | 1 | $2.50 | 667ERJ1GNF3831C (https://octopart.com/click/track?ai=8078&sig=0911227&sid=2401&ppid=44403109&vpid=447833062&ct=offers)
R16,R18 | 1k | RES 1kΩ 50mW 1% 0201 |  | R_0201_0603Metric | Panasonic | ERJ1GNF1001C (https://industrial.panasonic.com/ww/products/pt/general-purpose-chip-resistors/models/ERJ1GNF1001C) | 200 | $0.025 | $5.00 |  |  |  |  |  |  | NonStk |  | $0.027 | 1 | $5.32 | P122413CT-ND (https://octopart.com/click/track?c=1&ai=8078&sig=02b4475&sid=459&ppid=55419696&vpid=436711937&ct=offers) | 2007 |  | $0.028 | 10 | $5.54 | 2302336 (https://octopart.com/click/track?ai=8078&sig=04693d8&sid=819&ppid=55419696&vpid=139309632&ct=offers) |  |  |  |  |  |  | 980335 |  | $0.025 | 1 | $5.00 | 667ERJ1GNF1001C (https://octopart.com/click/track?ai=8078&sig=0133103&sid=2401&ppid=55419696&vpid=187838585&ct=offers) | 240000 |  | $0.025 | 1 | $5.00 | 85Y7483 (https://octopart.com/click/track?ai=8078&sig=0c7bd83&sid=2402&ppid=55419696&vpid=423915171&ct=offers) | 53000 |  |  | 1000 |  | 1797127 (https://octopart.com/click/track?ai=8078&sig=0546fa6&sid=10022&ppid=55419696&vpid=577025002&ct=offers)
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

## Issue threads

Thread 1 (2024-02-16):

Status?

janrinze, 2024-02-16:
Hi There,

Has this board been tested and does DP-Alt mode work?
I am very much interested in testing DP-Alt mode on the ECP5.

best regards,
Jan Rinze.

daglem, 2024-02-18:
Hi Jan,

When I designed the board, several of the key components were unobtainium, and unfortunately I haven't gotten back to it yet. The board has thus never been tested, and since it's fairly complex there is a risk it won't work at all.

The only of my boards that's been thoroughly tested so far is the [reDIP
SID](https://github.com/daglem/reDIP-SID).

Best regards,
Dag

Closed 2024-02-18.

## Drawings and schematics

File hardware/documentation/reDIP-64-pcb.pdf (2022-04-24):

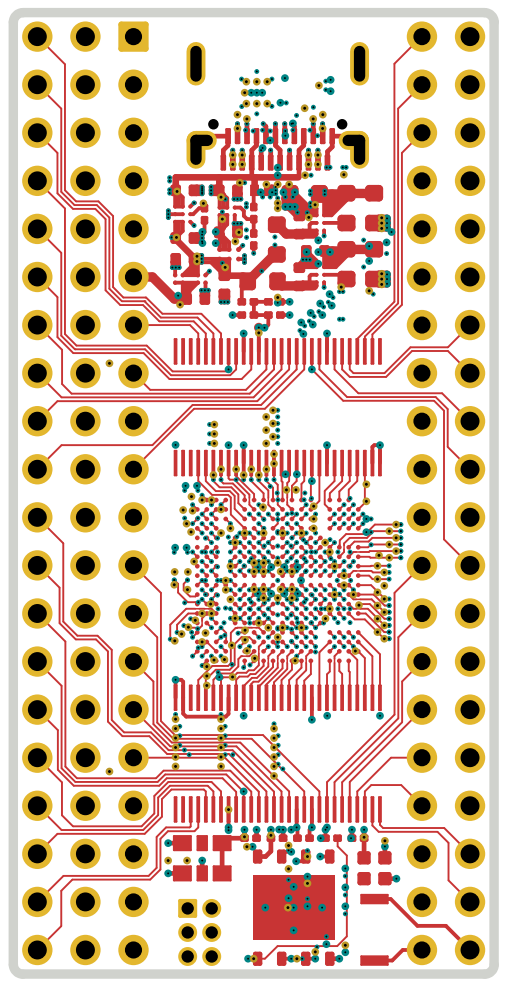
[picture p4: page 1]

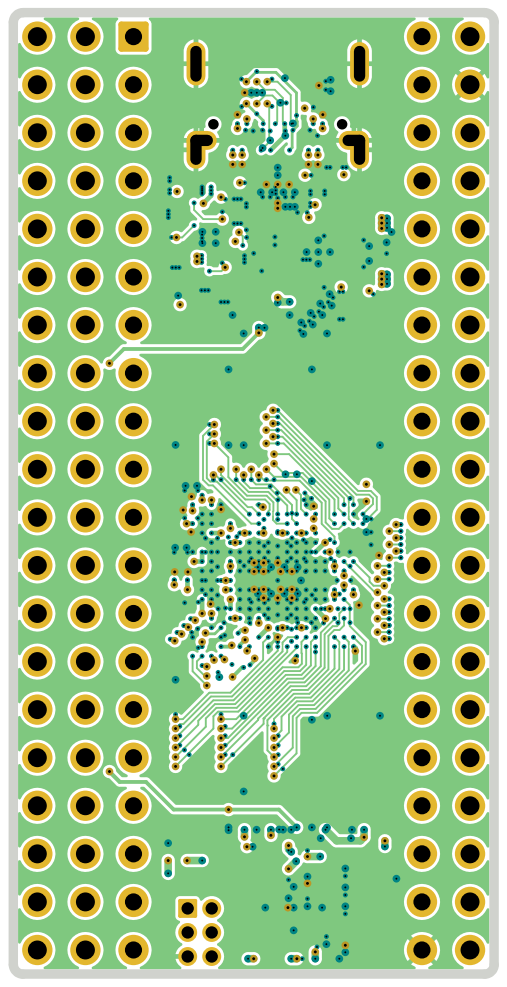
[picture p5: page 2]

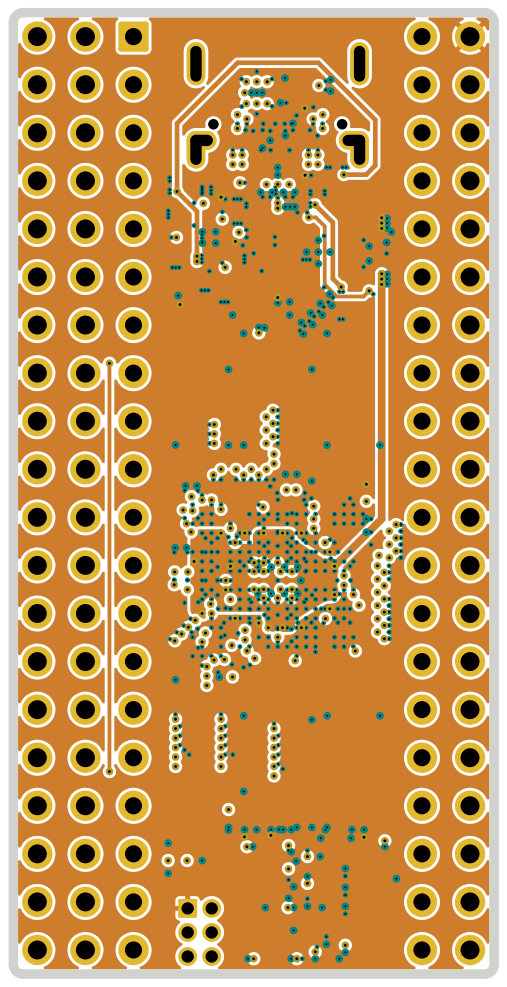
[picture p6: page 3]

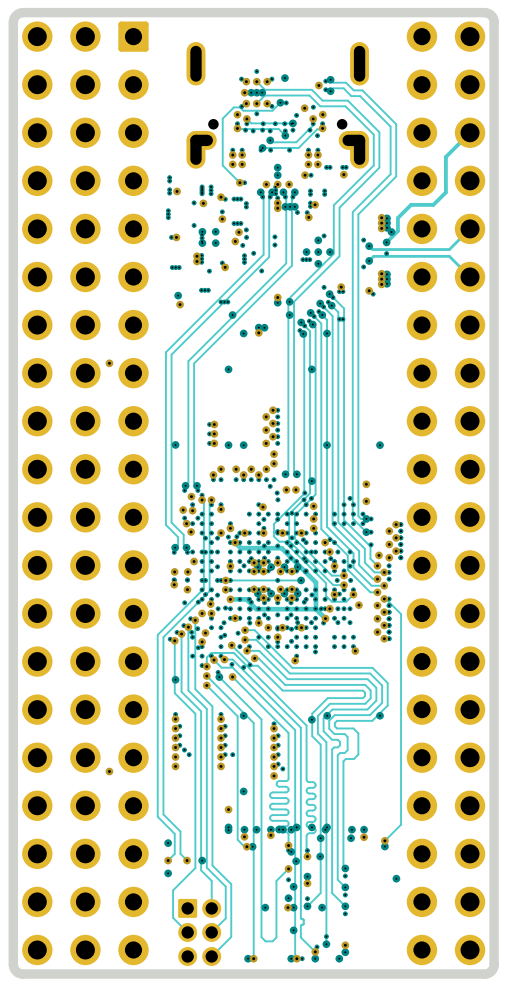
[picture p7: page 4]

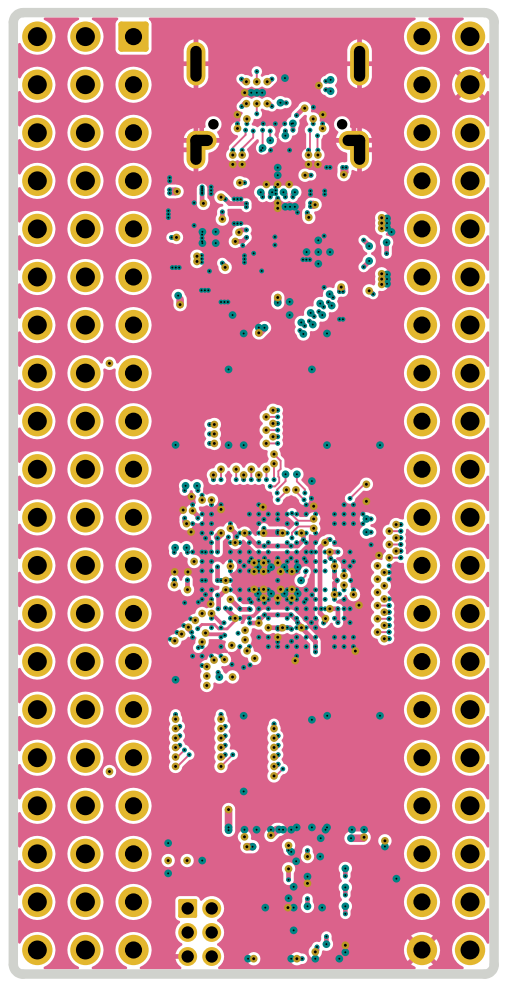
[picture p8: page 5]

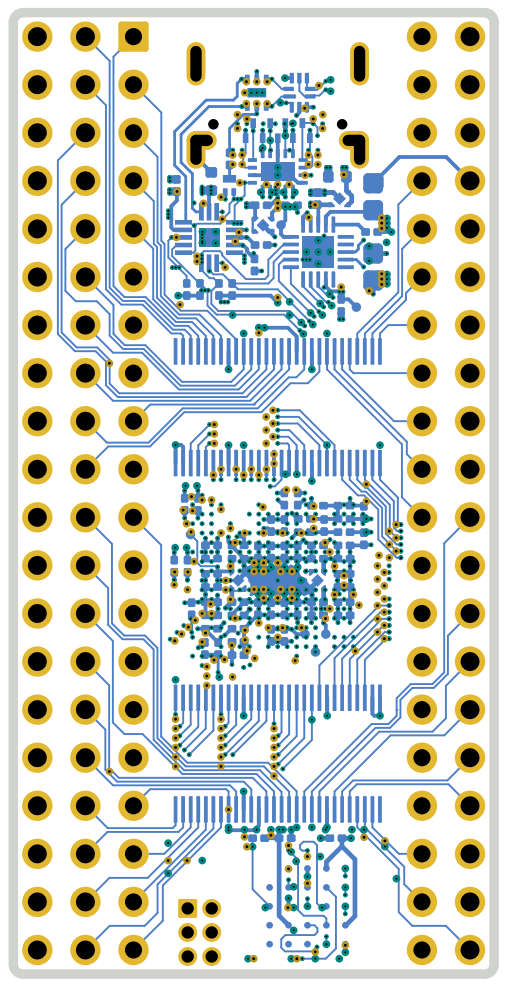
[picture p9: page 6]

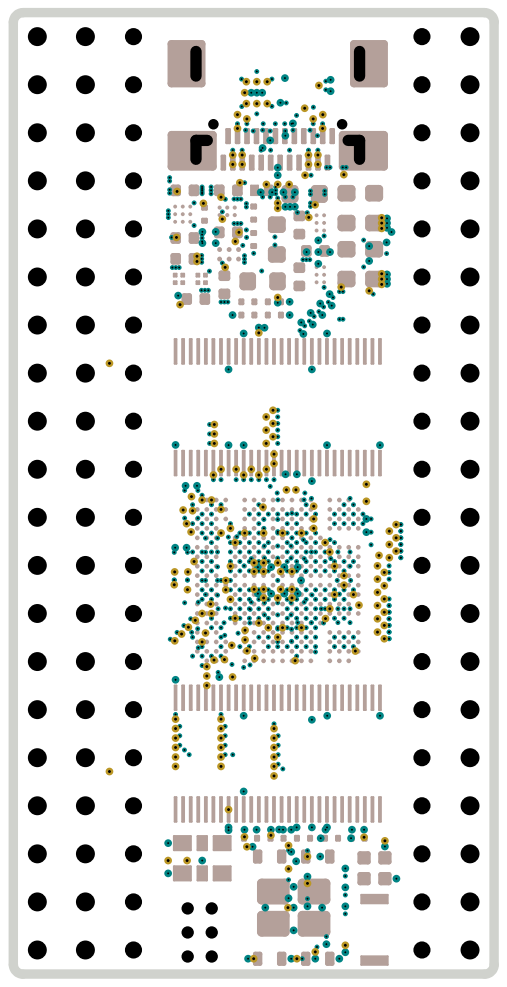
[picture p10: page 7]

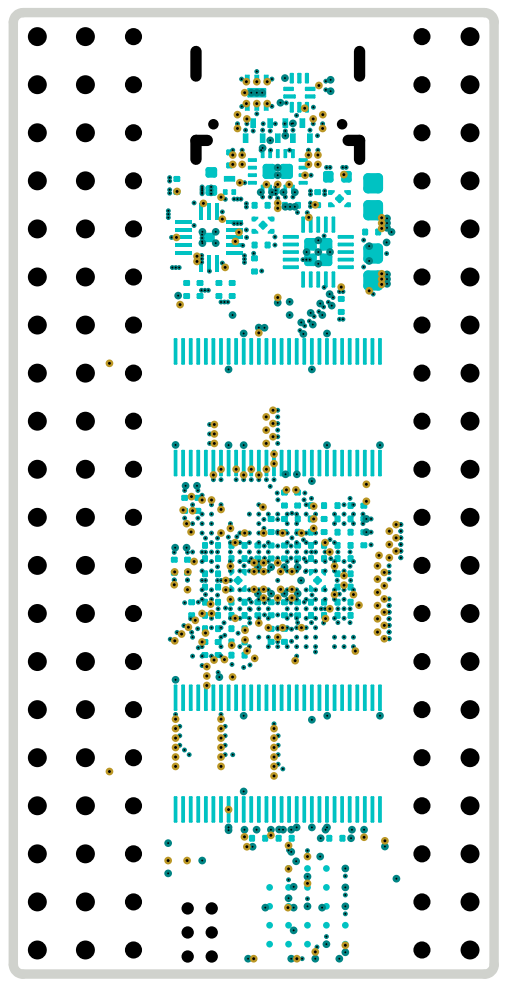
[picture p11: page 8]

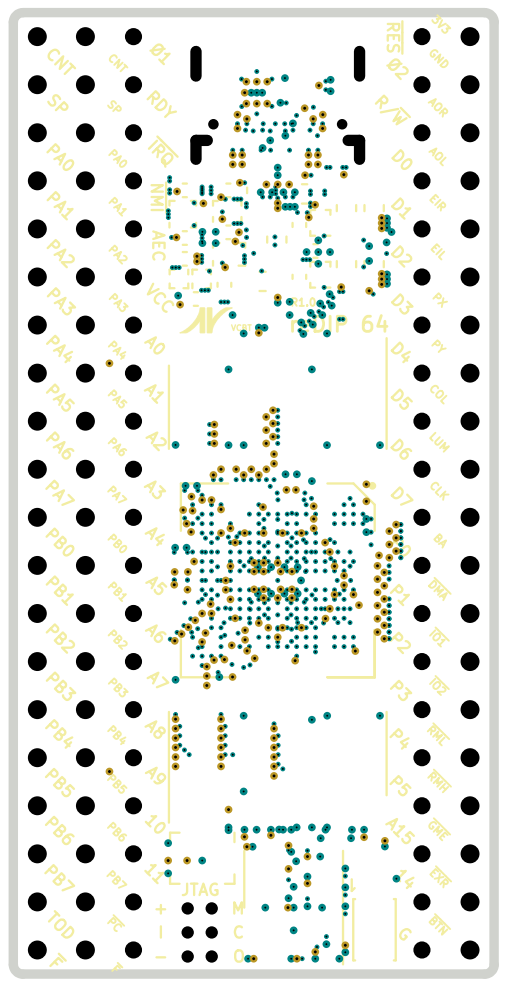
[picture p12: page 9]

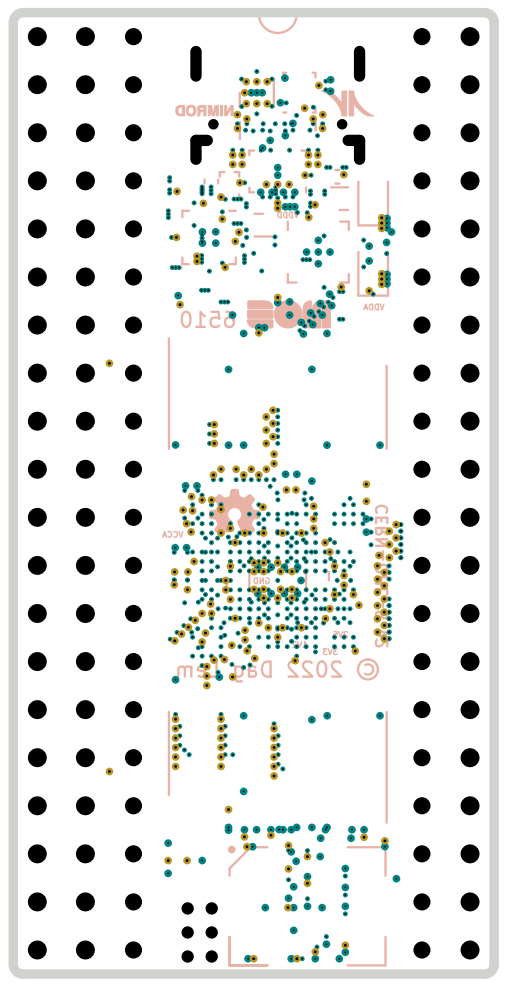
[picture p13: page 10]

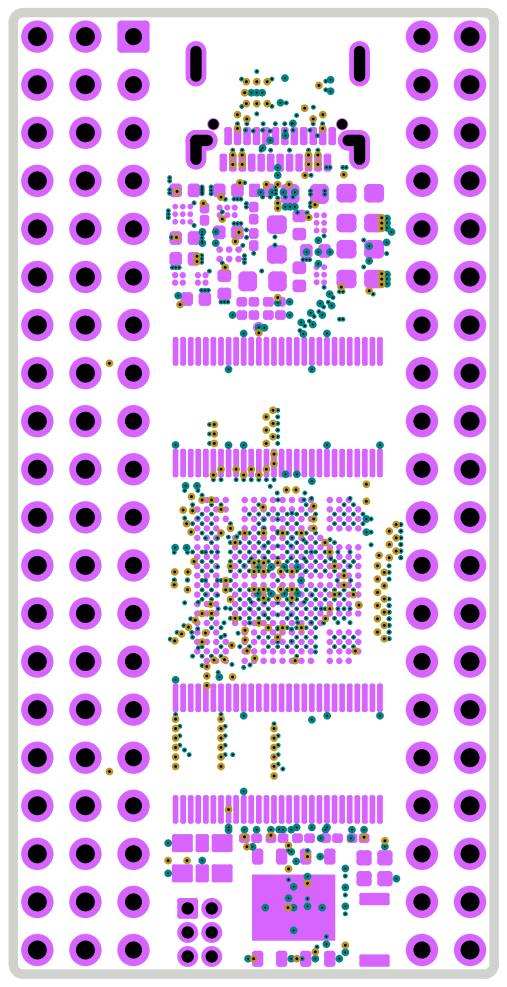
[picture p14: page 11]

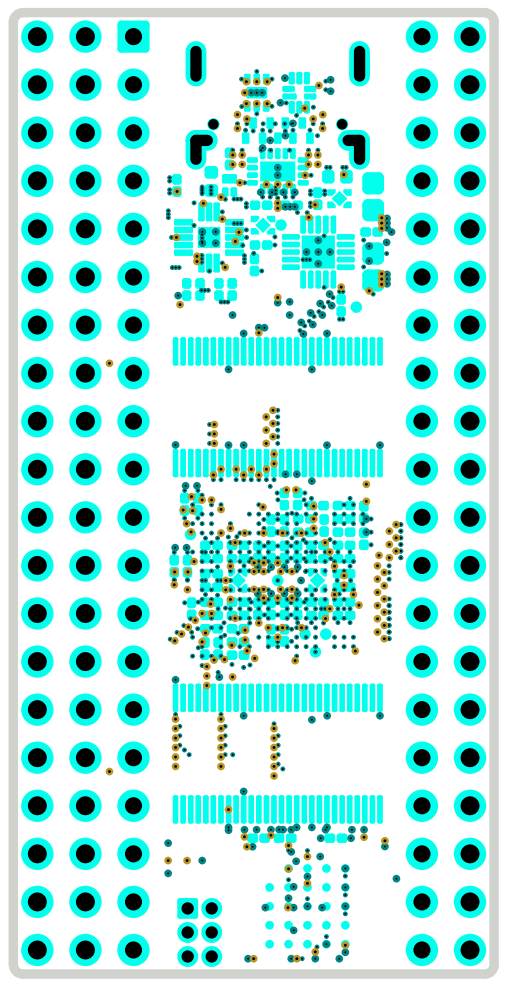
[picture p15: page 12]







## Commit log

2021-05-09 File cleanup
    [reDIP-64-Audio.kicad_sch, reDIP-64-Config.kicad_sch, reDIP-64-FPGA.kicad_sch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]
2021-06-12 Various improvements
    * Removed slash from sheet names
    * Reannotated schematics
    * Example derivation of clocks in schematics
    * Identical capacitors for DisplayPort main lanes and AUX
    * Replaced switch FSA2259UMX with FSUSB42UMX
    * Modified PCB physical stackup to (hopefully) be manufacturable
    * Only one microvia size (0.1mm)
    * Changed track width for differential pairs
    * Routing cleanups and improvements
    * Added files for manufacture
    * Updated README
    Many thanks for advice and help go to @azonenberg, @DX-MON, @gatecat,
    @smunaut, and @zyp.
    [reDIP-64-Audio.kicad_sch, reDIP-64-BOM.xlsx, reDIP-64-Config.kicad_sch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]
2021-06-12 Corrected BOM for C1-C6
    [reDIP-64-BOM.xlsx, reDIP-64-USB.kicad_sch]
2021-06-16 Added stitching vias and test points
    Thanks to @azonenberg for help and suggestions.
    [reDIP-64-Audio.kicad_sch, reDIP-64-Config.kicad_sch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]
2022-03-10 Updated all KiCad files to current format
    [reDIP-64-Audio.kicad_sch, reDIP-64-Config.kicad_sch, reDIP-64-FPGA.kicad_sch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]
2022-04-10 Revision 1.0
    * USB receptacle replaced with GCT USB4080-03-A / HRO TYPE-C-31-M-05
    * USB PD TCPC changed to PTN5110NHQ (FPF2286 has 15ms VBUS debounce time)
    * Complete rework of power section
    - Over-voltage protection on VBUS (FPF2286 / FPF2495C)
    - Bidirectional VCC (2 x TPS22916)
    - Replaced EOLed buck converters with FAN53610 / FAN53611
    - Replaced EOLed LDO for ECP5 VCCAUX with NCP115AMX250TCG
    - Replaced LDO for SGTL5000 VDDA with 3.3V version
    - Added separate LDO for SGTL5000 VDDD, avoiding overvoltage on ECP5 VCC
    * Bus switch changed to SN74CBT16211A, biased for level shifting
    * Registered I/O for FLASH / HyperRAM clock
    * Pin header changes:
    - Machined (round) pins for MOS651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
    [reDIP-64-Audio.kicad_sch, reDIP-64-BOM.xlsx, reDIP-64-Config.kicad_sch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]
2022-04-13 Replaced socket pin headers with socket adapter
    The socket adapter should hopefully *just* fit.
    [reDIP-64-BOM.xlsx, reDIP-64-Config.kicad_sch, reDIP-64-FPGA.kicad_sch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]
2022-04-14 A few improvements
    * Changed MCLK pullup to 4.7k
    * A few pin swaps for cleaner routing
    * Example pin headers in BOM
    * Replaced reduced lifetime "mobile only" capacitors
    [reDIP-64-Audio.kicad_sch, reDIP-64-BOM.xlsx, reDIP-64-Config.kicad_sch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]
2022-04-15 BOM correction, silk screen update
    [reDIP-64-BOM.xlsx, reDIP-64-Config.kicad_sch, reDIP-64.kicad_pcb]
2022-04-23 Audio upgrade
    * Changed from line out to headphone out with 10uF tantalum capacitors
    * PTN5110 decoupling capacitor QA
    [reDIP-64-Audio.kicad_sch, reDIP-64-BOM.xlsx, reDIP-64-Config.kicad_sch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]
2022-04-24 Further audio improvements
    * Additional power supply vias
    * Moved power and headphone out tracks away from under buck converters
    [reDIP-64.kicad_pcb]
2022-12-26 Global symbol update
    [reDIP-64-Audio.kicad_sch, reDIP-64-Config.kicad_sch, reDIP-64-FPGA.kicad_sch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]
2024-03-09 Updated to KiCad 7
    [reDIP-64-Audio.kicad_sch, reDIP-64-BOM.xlsx, reDIP-64-Config.kicad_sch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]
